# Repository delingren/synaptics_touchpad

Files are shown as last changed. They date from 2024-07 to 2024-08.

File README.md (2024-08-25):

# Laptop Touchpad Project

## Context

I harvested a touchpad from an old HP Envy Sleekbook 6 and wanted to use it as a standalone mouse. It's a clickpad. I.e. it has only one physical button and right click is simulated in software.

Goals:
* Cursor movements.
* Left click and right click (with two fingers).
* Two-finger scrolling.
* Make an enclosure with a USB-C connector.

Status:
* Everything listed above is fully implemented.
* No rigorous testing has been done.
* Some basic error handling is done.
* I have no problem using it as a daily drive.

Most laptop touchpads are made by Synaptics. They usually use a PS/2 interface. By default (i.e. without any special drivers), they can usually simulate a regular PS/2 mouse. I.e. they can report finger movements and button clicks. But that's about it. They don't support more sophisticated gestures we normally find on laptops. To achieve those gestures, we need to implement proprietary but published (with some caveats) Synaptics protocols, documented in [Synaptics PS/2 TouchPad Interfacing Guide](touchpad_RevB.pdf).

## Touchpad info
* Pulled from an HP Envy Sleekbook 6
* Synaptics chip # T1320A
* Pinout, reverse engineered after watching this [YouTube video](https://www.youtube.com/watch?v=XdznW0ZuzGo&t=381s)
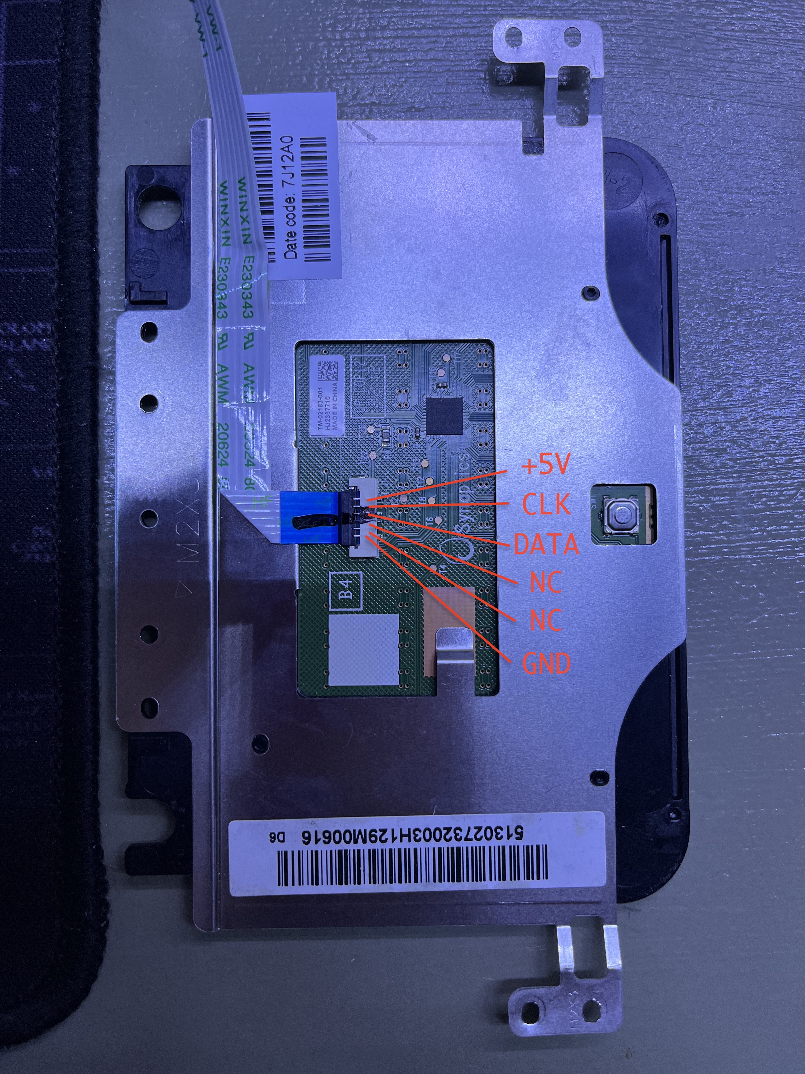
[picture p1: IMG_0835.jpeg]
Pinout


More info obtained from programatic queries, based on section 4.4. Information queries.

* Query 0x00 (Identify TouchPad): 01 47 18. 
  - Version 8.1

* Query 0x01 (Read TouchPad Modes): 20 87 40.
  - Model 0x0887

* Query 0x02 (Read Capabilities): D0 01 23
   - Extended capability: yes 
   - Extended queries: 13
   - Middle button: no
   - Model sub number: 01
   - Pass through: no
   - Low power: no
   - Multi finger report: yes
   - Can sleep: no
   - Four buttons: no
   - Ballitics: no
   - Multi finger detect: yes
   - Palm detect: yes

* Query 0x03 (Read Model ID): 01 E2 B1
  - Absolute mode: yes
  - Geometry: rectangule

* Query 0x06 (Read Serial Number Prefix): 00 00 00

* Query 0x07 (Read Serial Number Suffix): 00 00 00

* Query 0x08 (Read Resolutions): 2F 80 42
  - x units per mm: 47
  - y units per mm: 66
  
* Query 0x09 (Extended Model ID): 84 03 00
  - Light control: no
  - Peak detect: no
  - Glass pass: no
  - Vertical wheel: no
  - Ext. W mode: yes
  - H Scroll: no
  - V Scroll: no
  - Extended buttons: 0
  - Product ID: 0x00

* Query 0x0C (Continued Capabilities): 12 6C 00
  - Covered Pad Gesture: no
  - MultiFinger Mode: 1.0
  - Advanced Gestures: no
  - ClearPad: no
  - Reports Max Coordinates: yes
  - TouchButton Adjustable Threshold: no
  - InterTouch: yes
  - Reports Min Coordinates: yes
  - Uniform ClickPad: no (Hinged mechanism)
  - Reports V: yes
  - No Absolute Position Filter: no
  - Deluxe LEDs: no
  - ClickPad: One-button ClickPad

* Query 0x0D (Maximum Coordinates): B1 6B 94
  - max x: 5686 
  - max y: 4748

* Query 0x0F (Minimum Coordinates): 27 94 22
  - min x: 1256
  - min y: 1106

## Development setup
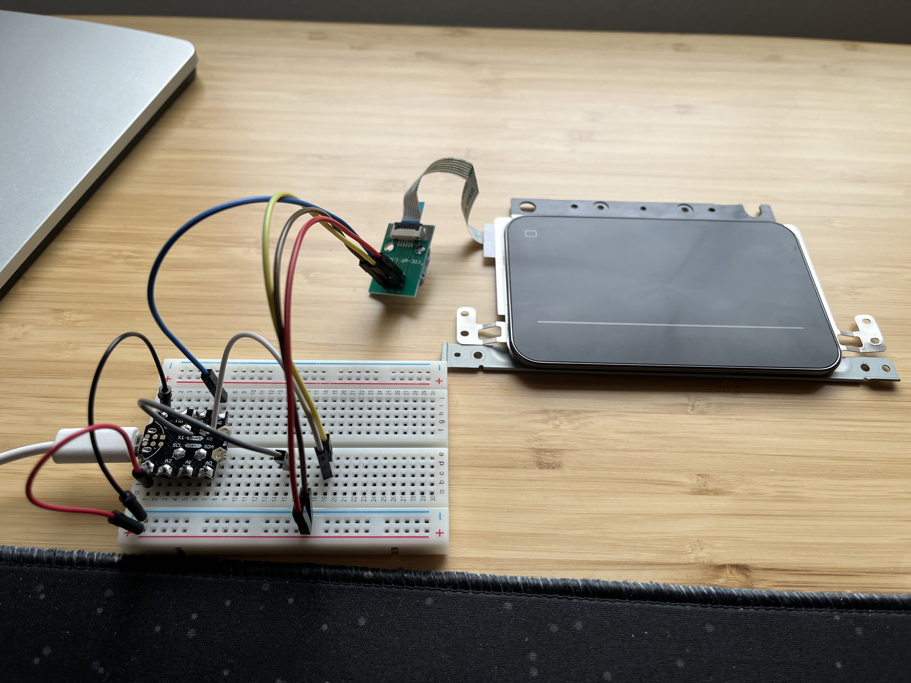
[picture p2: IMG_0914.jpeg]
Breadboard


## Implementing PS/2 on an MCU
I'm using an atmel mega32u4 to interface with the touchpad. Any Leonardo clone should work. The reason I picked this MCU is its native USB support. It also has a 5V logic level, which is what PS/2 uses, so there's no need for a level shifter. Another alternative is to use tinyusb library to bit bang USB protocol on supported MCUs. It's probably pretty straight-forward too.

Basically, I implemented syncrhonous writing, synchronous reading, and asynchronous reading. Synchronous writing because async writing is difficult to use. However, given the async nature of PS/2 protocol, it makes sense to have async, interrupt based reading. I.e. bits are transferred via interrupts and stored in a buffer. I have also implemented synchronous reading as a means to read responses after each write.

 I'm using [external interrupts](https://developerhelp.microchip.com/xwiki/bin/view/products/mcu-mpu/8-bit-avr/structure/extint/) to interact with the clock pin. So the clock pin needs to be one of these: 0, 1, 2, 3, 7 (D2, D3, D1, D0, E6, respectively). It's also possible to use pin change interrupts with slight changes to the code:

```
*(digitalPinToPCICR(clock_pin)) |= 1 << digitalPinToPCICRbit(clock_pin);
*(digitalPinToPCMSK(clock_pin)) |= 1 << digitalPinToPCMSKbit(clock_pin);

... 

ISR(PCINT0_vect) {
   ...
}
```

With the PS/2 protocol implemented, it's really straight-forward to interact the touchpad as a standard PS/2 mouse. The code is [here](https://github.com/delingren/ps2_mouse).

The rest of this doc focuses on the proprietary Synaptics expansion of the PS/2 protocol.

## Data packets
The touchpad sends 6-byte packets to the host. These packets contain information such as finger positions, pressure, width. This particular touchpad can detect 3 fingers. But it only reports the positions of two. When more than one finger is pressed, it reports the states of two fingers in alternating packets.

Since the communication is inevitably noisy, packets could be lost or altered. And it's not very critical to catch each and every frame. Some packets have distinctive features (e.g. fixed bits at certain places) and can be used as synchronization and recovery packets. So if an unexpected packet is received, I keep discarding packets until I'm in sync again.

## State machine logic
I am simulating the behaviour of a MacBook since that's what I'm used to. Most PC laptops behave the same too, with "tap to click" feature turned off. In the following text, whenever I say "two fingers", I mean two or more fingers.

For now, we only do tracking, scrolling, left and right buttons, where right button click is simulated with a two finger click, just like MacBook. Windows optionally supports this too, as long as the touchpad is multi-touch.

The logic is quite complicated. I might need to give it a little more thought and simplify a little. For now, we have three main valid states, identified by two state variables, finger count and button state. Finger count is the number of fingers on the pad. Button state is a bitmap representing the states of left and right buttons.

### Idle
This is where no fingers are on the touchpad. Conditions:
* finger count == 0
Note that even when there's no fingers are pressed, the button could still be pressed, by a non captive object such as a pen.

### Tracking
This is the state where we report the coordinate delta to the OS who will move the cursor accordingly. There are a couple of substates. conditions:
* finger count == 1 || finger count == 2 && button state != 0

When one finger is pressed, we're tracking regardless if the button is pressed. When two fingers are pressed and the button is *not* pressed, we always scroll. But if two fingers are pressed and the button is also pressed, we also track. This is MacBook's behaviour, which is different from Windows, at least Windows 11 on an HP Envy x360.

### Scrolling
This is the state where two fingers are on the pad and their vertical movements are treated as scrolling. Conditions:
* finger count == 2 || button state == 0

## Optimizations

### Smoothing
I found that if we faithfully report the finger positions in each frame, the cursor wobbles a lot, due to inherent noise and instability of human fingers. To mitigate, a few mechanisms are implemented:

* Averaging. Instead of reporting the position of each frame, I keep track of the average of last 5 frames, to remove sudden movements. I copied some of the logic from [VoodooPS2 driver](https://github.com/acidanthera/VoodooPS2/blob/master/VoodooPS2Trackpad/VoodooPS2TrackpadCommon.h).
* Noise threshold. If the delta between two frames is below a threshold, we assume it's not intentional. The number is emperical and I fine tuned it a few iterations to a place where I'm happy with false positives and false negatives.
* Snapping to the still position. When the finger has been saying still, we use a higher threshold, to make it a little "sticky" to start, but smoother once it's moving. 
* Fat finger and heavy finger. When the finger pressure is high or the width is big, we increase the threshold too, asssuming the finger is less stable. I am still not happy with this optimization. It's still pretty wobbly. But if I increase the threshold too much, it becomes too insensitive. The other day, when I was using a ThinkPad X1, I noticed this behaviour: if the finger width becomes big while tracking, it completely freezes the movement of that finger, until it is lifted, even if the width goes down again. I might want to prototype this behaviour and see if it helps.

### Precision Scrolling
Scrolling seems to have much less granularity. The HID report uses an integer. I find it quite jumpy to even report an amount of 1 in each frame. The reason is the frame rate is too high. But we can't report a fraction of a unit in a frame.

So, I decided to have two scrolling intentions: precision scrolling and fast scrolling. When the finger movements are slow and small, I only generate a report every few frames, and the movement is only 1. Once the speed has passed a certain threshold, I assume the user's intention is to quickly scroll over a big area. In this case, I report each frame and the amount is proportional to the actual movement.

### Freezing before button press and after button release
One thing I noticed is that the finger tends to be very unstable while pressing or releasing the button. So I try to freeze the finger movement (report a delta of 0) during these moments.
* Releasing is relatively easy. I have a global frame count which increases by 1 each time a packet arrives. When the button is released, I remember the frame count. Then in the next few frames, I always report the position delta as 0.
* Pressing is much trickier. By the time we realize a button has been pressed, the instability has already happened. In order to change frames retrospectively, I implemented a delayed reporting mechanism. Each time we want to send an HID report, we put it in a queue. And we send a report a few frames after it has been generated. We need to make this delay really small (just 3 or 4 frames) to be unnoticable.

## TODOs
* Make it more stable with thumb clicks. I'm still a little unhappy when I use the thumb to press the button and another finger to move the cursor. I use this a lot to select text. The thumb position is not very stable although my intention is to keep it still. This can probably be improved by checking the width of the finger, which is reported. A fat finger probably should be given more leeway when it comes to determining the movements. The idea I got from ThinkPad might be helpful here.
* ~~Make it more stable when lifting a finger. Lifting a finger tends to brush it over the touchpad and create an unwanted movement. Since we already have a delayed reporting in place, I think we can just go back and change the last few frames when we detect a finger lift.~~
* Tap as click. I was originally against this idea. But it's been growing on me after daily driving a bunch of PC laptops. It's kinda convenient, I have to admit. And it shouldn't be too hard to implement: a short session where the finger movements have never exceeded the noise threshold, we send a button down and a button up reports.
* Horizontal scrolling. I think this is a standard USB HID feature and should be relatively easy to implement. I need to check the USB HID spec, which is very dry to read.
* Three finger swipes as back or forward button. USB HID supports at least 5 buttons so this should be doable.
* Zooming with two fingers. I'm not sure if this is doable, unless we make it into a digitizer.
* Velocity tracking and inertia. If we keep track of the speed of the movements, we can implement a lot of interesting features. One example is inertia, where if you've been scrolling, after the fingers have been released, it still keeps going for a little, slowing down gradually. Another potential application is to keep the noise tolerance high at zero/very low speed, reducing it once the fingers are moving. This way, we can provide better precision control at low speed.

## Enclosure
I designed the enclosure in Fusion 360 and 3D printed it. The stl and original f3d files can be found under `enclosure` folder. I used a ProMicro clone with a USB-C connector. It has the same footprint as the original ProMicro.

The end result:

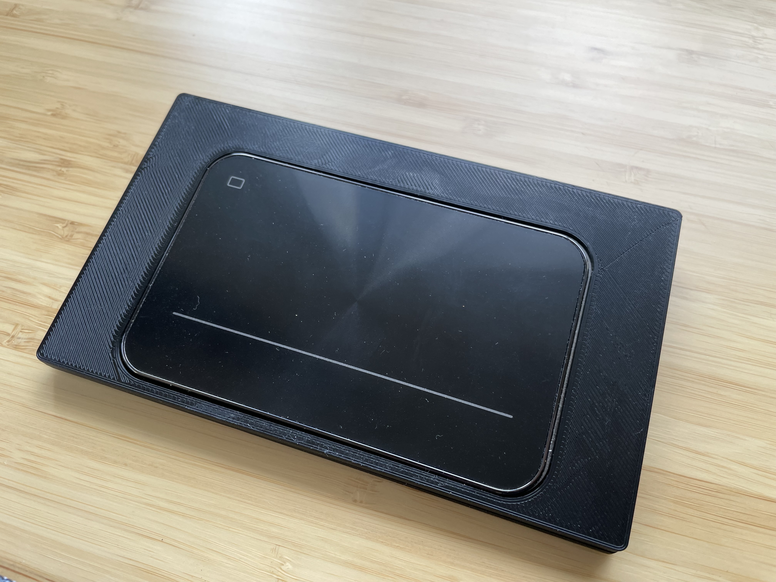
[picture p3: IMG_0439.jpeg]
End result


In action:

In action

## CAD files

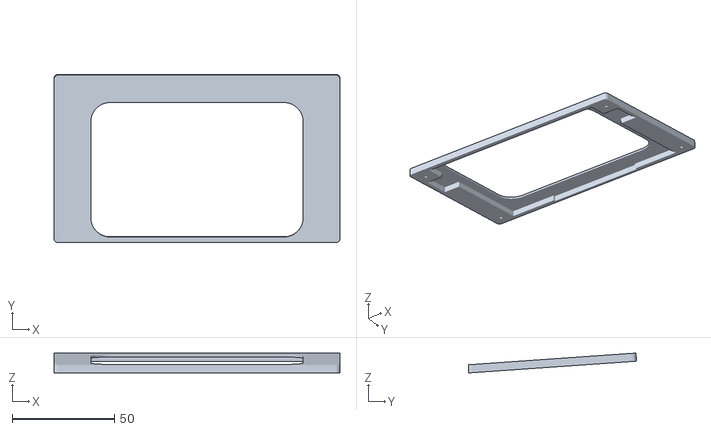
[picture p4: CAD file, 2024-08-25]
enclosure/upper.stl
140.0 x 82.3 x 9.75

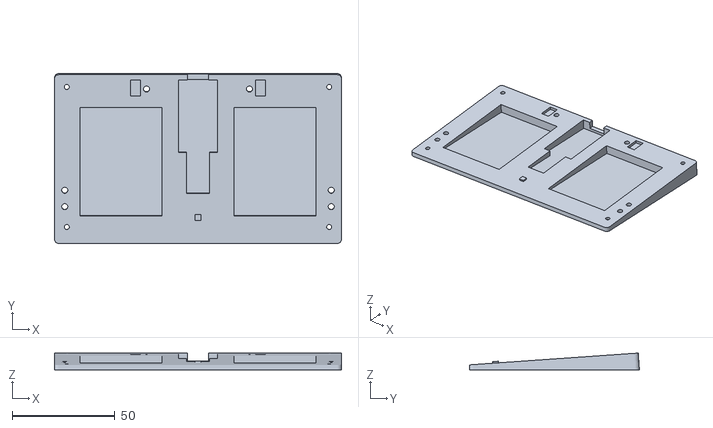
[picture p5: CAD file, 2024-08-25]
enclosure/lower.stl
140.0 x 82.9 x 8.25

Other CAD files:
enclosure/enclosure.f3d

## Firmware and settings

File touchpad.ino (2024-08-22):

// The MIT License (MIT)

// Copyright (c) 2024 Deling Ren

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
#include "src/hid.h"
#include "src/ps2.h"
#include "src/synaptics.h"

#ifndef min
#define min(a, b) ((a) < (b) ? (a) : (b))
#endif

#ifndef max
#define max(a, b) ((a) > (b) ? (a) : (b))
#endif

#ifndef sign
#define sign(x) ((x) > 0 ? (1) : ((x) < 0 ? (-1) : (0)))
#endif

// All the following consts are empirical and may vary from person to person and
// from device to device. These values are a good place to start. I may keep
// fine turning them.

// When finger is held *still*, the maximum flucation from frame to frame in mm.
const float noise_threshold_tracking_mm = 0.08;
const float noise_threshold_scrolling_mm = 0.09;

// In order to retrospectively change the frames in the past, we delay reporting
// for a few frames. This needs to be short enough that it's not perceptible.
const int frames_delay = 6;
// After the button is released, we freeze for a few frames since the finger is
// likely going to be very unstable. Since it's very hard to release the button
// and start moving immediately, it's OK to keep this frozen period relatively
// long.
const int frames_stablization = 15;

// HID units per mm, when tracking.
const float scale_tracking_mm = 12.0;
// HID units per mm, when scrolling.
const float scale_scroll_mm = 1.6;
// Cutoff speed between slow and fast scrolling, in mm/frame.
const float slow_scroll_threshold_mm = 2.0;
// Max distance between two frames.
const float max_delta_mm = 3;
// The delta in either direction within which is considered normal movements
// between frames while scrolling at a moderate speed.
const int proximity_threshold_mm = 15;
// The amount of scroll per detent, in HID units
const float slow_scroll_amount = 0.20F;

// HID units per raw unit, when tracking.
float scale_tracking_x, scale_tracking_y;
// UID units per raw unit, when scrolling.
float scale_scroll;
// Max fluctuation from frame to frame in raw units.
float noise_threshold_tracking_x, noise_threshold_tracking_y;

float noise_threshold_scrolling_y;

// Max distance from frame to frame in raw units.
float max_delta_x, max_delta_y;
// Cutoff speed between slow and fast scrolling, in raw units per frame.
float slow_scroll_threshold;
// The delta within which is considered normal movements between frames while
// scrolling at a moderate speed.
float proximity_threshold_x, proximity_threshold_y;

struct finger_state {
  SimpleAverage<int, 5> x;
  SimpleAverage<int, 5> y;
  short z;
};

struct report {
  uint8_t buttons;
  int8_t x;
  int8_t y;
  int8_t scroll;
};

// In reality we don't really need a ring buffer for packets. A 16MHz ATMega32U4
// can easily handle 80 frames per second without skipping frames.
RingBuffer<uint64_t, 4> packets;
RingBuffer<report, 32> reports;

static unsigned long global_tick = 0;
static unsigned long session_started_tick = 0;
static unsigned long button_released_tick = 0;

// State of primary and secondary fingers. We only keep track of two since this
// touchpad doesn't report the position of the 3rd and doesn't register the 4th.
static finger_state finger_states[2];
static short finger_count = 0;
static uint8_t button_state = 0;  // bit 0: L, bit 1: R

const uint8_t LEFT_BUTTON = 0x01;
const uint8_t RIGHT_BUTTON = 0x02;

void byte_received(uint8_t data) {
  static uint64_t buffer = 0;
  static int index = 0;

  if (index == 0 && (data & 0xc8) != 0x80) {
    Serial.print("Unexpected byte0 data ");
    Serial.println(data, HEX);

    index = 0;
    buffer = 0;
    return;
  }

  if (index == 24 && (data & 0xc8) != 0xc0) {
    Serial.print("Unexpected byte3 data ");
    Serial.println(data, HEX);

    index = 0;
    buffer = 0;
    return;
  }

  buffer |= ((uint64_t)data) << index;
  index += 8;
  if (index == 48) {
    packets.push_back(buffer);
    index = 0;
    buffer = 0;
  }
}

void process_pending_packet(uint64_t packet) {
  global_tick++;
  uint8_t w =
      (packet >> 26) & 0x01 | (packet >> 1) & 0x2 | (packet >> 2) & 0x0C;

  // When parsing packets, we queue the reports instead of send them directly.
  // Then we delay sending them for a few frames, to give us an opportunity to
  // retrospectively change the reports.
  // We produce at most one report per frame. So we only need to send one
  // pending report per frame. Once all activities ceased, the touchpad keeps
  // sending packets with x, y, and z all set to 0 for one second. And we only
  // report the first one. That means, we have plenty of time to clear up the
  // report queue, which we need to do. Otherwise the queue will get clogged up
  // soon, and reports leak to the next session, causing weird behaviors.
  if (global_tick - session_started_tick >= frames_delay) {
    if (!reports.empty()) {
      report item = reports.pop_front();
      hid::report(item.buttons, item.x, item.y, item.scroll);
    }
  }

  switch (w) {
    case 3:  // pass through
      return;
    case 2:  // extended w mode
      parse_extended_packet(packet);
      return;
    default:
      parse_primary_packet(packet, w);
      return;
  }
}

float to_hid_value(float value, float threshold, float scale_factor) {
  const float hid_max = 127.0F;
  if (abs(value) < threshold) {
    return 0;
  }
  return sign(value) * min(max(abs(value) * scale_factor, 1.0F), hid_max);
}

void queue_report(uint8_t buttons, int8_t x, int8_t y, float scroll) {
  static float scroll_amount_rollover = 0;
  report item = {.buttons = buttons};
  if (button_released_tick != 0 &&
      global_tick - button_released_tick < frames_stablization) {
    // When a button is released, we freeze the next few frames.
    item.x = 0;
    item.y = 0;
    item.scroll = 0;
  } else {
    if (scroll > -1.0F && scroll < 1.0F) {
      scroll_amount_rollover += scroll;
      if (scroll_amount_rollover >= 1.0F) {
        scroll = 1.0F;
        scroll_amount_rollover -= 1.0F;
      } else if (scroll_amount_rollover <= -1.0F) {
        scroll = -1.0F;
        scroll_amount_rollover += 1.0F;
      } else {
        scroll = 0;
      }
    }
    item.x = x;
    item.y = y;
    item.scroll = scroll;
  }
  reports.push_back(item);
}

void parse_primary_packet(uint64_t packet, int w) {
  // Reference: Section 3.2.1, Figure 3-4
  int x = (packet >> 32) & 0x00FF | (packet >> 0) & 0x0F00 |
          (packet >> 16) & 0x1000;
  int y = (packet >> 40) & 0x00FF | (packet >> 4) & 0x0F00 |
          (packet >> 17) & 0x1000;
  short z = (packet >> 16) & 0xFF;
  // w is width only if it >= 4. otherwise it encodes finger count
  short width = max(w, 4);

  // A clickpad reprots its button as a middle/up button. This logic needs to
  // change completely if the touchpad is not a clickpad (i.e. it has physical
  // buttons).
  bool button = (packet >> 24) & 0x01;
  int new_finger_count = 0;
  if (z == 0) {
    new_finger_count = 0;
  } else if (w >= 4) {
    new_finger_count = 1;
  } else if (w == 0) {
    new_finger_count = 2;
  } else if (w == 1) {
    new_finger_count = 3;
  }

  if (finger_count == 0 && new_finger_count > 0) {
    session_started_tick = global_tick;
  }

  /* Mechanisms to smooth the movements. */

  // When a button is pressed, we retrospectively freeze the previous frames,
  // since the movements tend to be jerky when releasing a button.
  if (button && button_state == 0) {
    int size = reports.size();
    for (int i = 0; i < size; i++) {
      reports[i].x = 0;
      reports[i].y = 0;
      reports[i].scroll = 0;
    }
  }

  // When a button is released, we freeze the next few frames, since the
  // movements tend to be jerky when pressing a button.
  if (!button && button_state != 0) {
    button_released_tick = global_tick;
  }

  // When a finger is lifted, we restrospectively freeze the previous
  // frames, since the movements tend to be jerky when lifting a finger.
  if (new_finger_count < finger_count) {
    for (int i = 0; i < reports.size(); i++) {
      reports[i].x = 0;
      reports[i].y = 0;
      reports[i].scroll = 0;
    }
  }

  /* Update state variables. */
  if (new_finger_count > finger_count) {
    // A finger has been added. Reset state for that finger.
    finger_states[1].x.reset();
    finger_states[1].y.reset();
    if (finger_count == 0) {
      finger_states[0].x.reset();
      finger_states[0].y.reset();
    }
  }

  int delta_x = 0, delta_y = 0;

  if (new_finger_count > 0) {
    finger_states[0].z = z;

    int prev_x = finger_states[0].x.average();
    int new_x = finger_states[0].x.filter(x);
    if (prev_x > 0 && new_finger_count == finger_count) {
      delta_x = new_x - prev_x;
    }

    int prev_y = finger_states[0].y.average();
    int new_y = finger_states[0].y.filter(y);
    if (prev_y > 0 && new_finger_count == finger_count) {
      delta_y = new_y - prev_y;
    }
  }

  if (new_finger_count < finger_count) {
    // A finger has been released.
    if (finger_count == 2) {
      // 2 fingers -> 1 finger
      // When a primary finger is released, the secondary becomes the primary.
      // We determine if that is happening by checking if the finger location is
      // close to the previous secondary finger. proximity_threshold is an
      // emperical number and not always reliable. We err on the conservative
      // side. If we can't be sure, just reset the state. This could result in a
      // slightly jerky cursor movement.
      if (abs(x - finger_states[0].x.average()) >= proximity_threshold_x ||
          abs(y - finger_states[0].y.average()) >= proximity_threshold_y) {
        if (abs(x - finger_states[1].x.average()) < proximity_threshold_x &&
            abs(y - finger_states[1].y.average()) < proximity_threshold_y) {
          finger_states[0] = finger_states[1];
        } else {
          finger_states[0].x.reset();
          finger_states[0].y.reset();
        }
      }
    } else {
      // 3 fingers -> 2 fingers or 1 finger, or all fingers have been lifted.
      // Let's not bother. Just reset both fingers.
      finger_states[0].x.reset();
      finger_states[0].y.reset();
      finger_states[1].x.reset();
      finger_states[1].y.reset();
    }
  }

  if (finger_count == 1 && new_finger_count == 1 &&
      (abs(delta_x) >= max_delta_x || abs(delta_y) >= max_delta_y)) {
    // In rare occasions where a finger is released and another is pressed in
    // the same frame, we don't see a finger count change but a big jump in
    // finger position. In this case, reset the position and start over.
    // This solution isn't ideal. A rather big jump could happen when the
    // fingers are moving very fast. A more reliable approach would be based
    // on the recent velocity of the finger movements. But it's complicated
    // and expensive. Both scenarios just described are edge cases and the user
    // is probably just fooling around.
    finger_states[0].x.reset();
    finger_states[0].y.reset();
    delta_x = 0;
    delta_y = 0;
  }

  finger_count = new_finger_count;

  /* State machine logic */
  if (finger_count == 0) {
    // idle
    if (button_state == 0 && button) {
      button_state = new_finger_count < 2 ? LEFT_BUTTON : RIGHT_BUTTON;
      queue_report(button_state, 0, 0, 0);
    } else if (button_state != 0 && !button) {
      button_state = 0;
      queue_report(0, 0, 0, 0);
    }
  } else if (finger_count >= 2 && button_state == 0) {
    // scrolling
    if (button) {
      // It's OK to change between left and right while scrolling.
      button_state = new_finger_count > 1 ? RIGHT_BUTTON : LEFT_BUTTON;
    } else {
      button_state = 0;
    }

    // Since we're scrolling, we are here every other frame. So we should double
    // the noise threshold.
    float scroll_amount =
        to_hid_value(delta_y, noise_threshold_scrolling_y, scale_scroll);
    if (abs(delta_y) <= slow_scroll_threshold) {
      scroll_amount = sign(scroll_amount) * slow_scroll_amount;
    }
    queue_report(button_state, 0, 0, scroll_amount);
  } else if (finger_count == 1 || finger_count >= 2 && button_state != 0) {
    // 1-finger tracking or 2-finger tracking
    if (button) {
      // If the button is already pressed, we don't change between left and
      // right while dragging.
      if (button_state == 0) {
        button_state = new_finger_count > 1 ? RIGHT_BUTTON : LEFT_BUTTON;
      }
    } else {
      button_state = 0;
    }
    // If there are multiple fingers pressed, normal packets and secondary
    // packets are alternated. So we should double the threshold.
    float threshold_multiplier = finger_count == 1 ? 1.0 : 2.0;
    // Serial.print("Width: ");
    // Serial.print(width);
    // Serial.print(" Pressure: ");
    // Serial.println(z);

    if (width > 4) {
      // Fat finger
      threshold_multiplier *= 1.0F + (width - 4.0F) / 4.0F;
    }
    if (z >= 60) {
      // Heavy finger
      threshold_multiplier *= 1.0F + (z - 60.0F) / 40.0F;
    }

    float delta_x_mm = ((float)delta_x) / ((float)synaptics::units_per_mm_x);
    float delta_y_mm = ((float)delta_y) / ((float)synaptics::units_per_mm_y);
    // Precision for low speed and range for high speed. If there are more than
    // one finger the speed needs to be doubled.
    float velocity = sqrt(delta_x_mm * delta_x_mm + delta_y_mm * delta_y_mm);
    if (finger_count > 1) {
      velocity *= 2;
    }
    float scale_multiplier = 1.0F + velocity * 0.5F;  // Emperical constant

    int8_t delta_x_hid =
        to_hid_value(delta_x, noise_threshold_tracking_x * threshold_multiplier,
                     scale_tracking_x * scale_multiplier);
    int8_t delta_y_hid = -to_hid_value(
        delta_y, noise_threshold_tracking_y * threshold_multiplier,
        scale_tracking_y * scale_multiplier);
    queue_report(button_state, delta_x_hid, delta_y_hid, 0);
  }
}

void parse_extended_packet(uint64_t packet) {
  uint8_t packet_code = (packet >> 44) & 0x0F;
  if (packet_code == 1) {
    // Reference: Section 3.2.9.2. Figure 3-14
    int x = (packet >> 7) & 0x01FE | (packet >> 23) & 0x1E00;
    int y = (packet >> 15) & 0x01FE | (packet >> 27) & 0x1E00;
    short z = (packet >> 39) & 0x1D | (packet >> 23) & 0x60;

    if (x == 0 || y == 0 || z == 0) {
      finger_states[1].x.reset();
      finger_states[1].y.reset();
      return;
    }

    int prev_x = finger_states[1].x.average();
    int new_x = finger_states[1].x.filter(x);
    int delta_x = prev_x == 0 ? 0 : new_x - prev_x;

    int prev_y = finger_states[1].y.average();
    int new_y = finger_states[1].y.filter(y);
    int delta_y = prev_y == 0 ? 0 : new_y - prev_y;

    if (abs(delta_x) >= max_delta_x || abs(delta_y) >= max_delta_y) {
      // Sometimes when a 2nd or 3rd finger is released, we receive a secondary
      // finger position before the finger count change. In this case, the new
      // secondary finger is not necessarily the same physical finger as
      // previous one. Not sure if this is by design or due to a packet loss.
      // In either case, we should not report this position change to avoid
      // jerky movements. Instead, reset the secondary finger state and start
      // over.
      finger_states[1].x.reset();
      finger_states[1].y.reset();
      delta_x = 0;
      delta_y = 0;
    }

    finger_states[1].x.filter(x);
    finger_states[1].y.filter(y);
    finger_states[1].z = z;

    // TODO: use velocity and z value to adjst the multiplier here too, just
    // like the primary frames. We don't have width info though.
    if (finger_count >= 2 && button_state == 0) {
      // Since we are parsing secondary packets, we are here every other frame,
      // so we should double the noise threshold.
      float scroll_amount =
          to_hid_value(delta_y, noise_threshold_scrolling_y, scale_scroll);
      if (abs(delta_y) <= slow_scroll_threshold) {
        scroll_amount = sign(scroll_amount) * slow_scroll_amount;
      }
      queue_report(button_state, 0, 0, scroll_amount);
    } else {
      int8_t delta_x_hid = to_hid_value(
          delta_x, noise_threshold_tracking_x * 2.0F, scale_tracking_x);
      int8_t delta_y_hid = -to_hid_value(
          delta_y, noise_threshold_tracking_y * 2.0F, scale_tracking_y);
      queue_report(button_state, delta_x_hid, delta_y_hid, 0);
    }
  }
}

void setup() {
  Serial.begin(115200);
  hid::init();
  // The pins are quite noisy on startup. Let's wait for a bit before starting
  // the touchpad. 500ms seems to be a good time. It's still not bullet proof
  // but the error handling mechanism seems to be able to recover every time.
  delay(500);
  ps2::begin(0, 1, byte_received);
  ps2::reset();
  synaptics::init();

  scale_tracking_x = scale_tracking_mm / synaptics::units_per_mm_x;
  scale_tracking_y = scale_tracking_mm / synaptics::units_per_mm_y;
  scale_scroll = scale_scroll_mm / synaptics::units_per_mm_y;
  noise_threshold_tracking_x =
      noise_threshold_tracking_mm * synaptics::units_per_mm_x;
  noise_threshold_tracking_y =
      noise_threshold_tracking_mm * synaptics::units_per_mm_y;
  noise_threshold_scrolling_y =
      noise_threshold_scrolling_mm * synaptics::units_per_mm_y;
  max_delta_x = max_delta_mm * synaptics::units_per_mm_x;
  max_delta_y = max_delta_mm * synaptics::units_per_mm_y;
  slow_scroll_threshold = slow_scroll_threshold_mm * synaptics::units_per_mm_y;
  proximity_threshold_x = proximity_threshold_mm * synaptics::units_per_mm_x;
  proximity_threshold_y = proximity_threshold_mm * synaptics::units_per_mm_y;
}

void loop() {
  if (!packets.empty()) {
    uint64_t packet = packets.pop_front();
    process_pending_packet(packet);
  }
}

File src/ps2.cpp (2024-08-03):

// The MIT License (MIT)

// Copyright (c) 2024 Deling Ren

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
#include <Arduino.h>
#include "ps2.h"

namespace ps2 {
// Sample code for interacting with a PS2 mouse from a mega32u4.
// Writing is synchronous. Async write is hard for the client to handle.
namespace {  // anonymous namespace to hide code from the client.
// On atmel mega32u4, clock_pin needs to be one of these: 0, 1, 2, 3, 7,
// otherwise, we need to use pin change interrupt.
int clock_pin_;
int data_pin_;
void (*byte_received_)(uint8_t);

void pull_low(uint8_t pin) {
  pinMode(pin, OUTPUT);
  digitalWrite(pin, LOW);
}

void pull_high(uint8_t pin) { pinMode(pin, INPUT_PULLUP); }

uint8_t read_bit() {
  pinMode(data_pin_, INPUT);
  return digitalRead(data_pin_);
}

void write_bit(uint8_t data) {
  pinMode(data_pin_, OUTPUT);
  digitalWrite(data_pin_, data);
}

void wait_clock(uint8_t value) {
  if (value == LOW) {
    pinMode(clock_pin_, INPUT_PULLUP);
  } else {
    pinMode(clock_pin_, INPUT);
  }

  unsigned long millis_start = millis();
  while (digitalRead(clock_pin_) != value) {
    if (millis() - millis_start > 25) {
      Serial.println("wait_clock timed out.");
      return;
    }
  }
}

volatile int receive_index = 0;
volatile uint8_t receive_buffer = 0;
volatile uint8_t parity = 0;

void disable_interrupt() {
  cli();
  // We need to abandon the ongoing read from the device.
  // Otherwise it'll go haywire next time we enable interrupt.
  receive_index = 0;
  receive_buffer = 0;
  parity = 0;
}

void enable_interrupt() { sei(); }

void bit_received() {
  int clock = digitalRead(clock_pin_);
  if (clock != LOW) {
    return;
  }

  int bit = read_bit();
  if (receive_index == 0) {
    // Start bit
    if (bit != LOW) {
      Serial.println("Start bit error.");
    }
  } else if (receive_index >= 1 && receive_index <= 8) {
    // Payload bit
    receive_buffer |= bit << (receive_index - 1);
    parity ^= bit;
  } else if (receive_index == 9) {
    // Parity bit
    parity ^= bit;
    if (parity != 1) {
      Serial.println("Parity bit error.");
    }

  } else if (receive_index == 10) {
    // Stop bit
    if (bit != HIGH) {
      Serial.println("Stop bit error.");
    }
    byte_received_(receive_buffer);
    receive_buffer = 0;
    receive_index = 0;
    parity = 0;
    return;
  }

  receive_index++;
}

// Reads a byte synchronously. This should only be called from write_byte() to
// read the response and shouldn't be called by the client.
uint8_t read_byte() {
  // Start bit
  wait_clock(LOW);
  uint8_t start_bit = read_bit();
  if (start_bit != LOW) {
    Serial.println("Start bit error.");
  }
  wait_clock(HIGH);

  uint8_t data = 00;
  uint8_t parity = 0;
  for (int i = 0; i < 8; i++) {
    wait_clock(LOW);
    uint8_t bit = read_bit();
    wait_clock(HIGH);

    data |= bit << i;
    parity ^= bit;
  }

  wait_clock(LOW);
  parity ^= read_bit();
  wait_clock(HIGH);
  if (parity != 1) {
    Serial.println("Parity error.");
  }

  wait_clock(LOW);
  uint8_t stop = read_bit();
  if (stop != 1) {
    Serial.println("Stop bit error.");
  }
  pull_low(clock_pin_);
  delayMicroseconds(50);
  pull_high(clock_pin_);

  return data;
}
}  // namespace

bool write_byte(uint8_t data) {
  // Bring CLK low for 100 us.
  pull_low(clock_pin_);
  delayMicroseconds(100);
  // Bring DATA low.
  pull_low(data_pin_);
  // Release CLK
  pull_high(clock_pin_);
  // Now we are in the request-to-send state.

  uint8_t const stop = 1;
  uint8_t parity = 1;

  // bits 0 - 7: payload
  for (int i = 0; i < 8; i++) {
    // Get the LSB
    uint8_t bit = data & 0x01;
    // Update parity
    parity ^= bit;
    // Shift data for next iteration
    data >>= 1;

    // Device samples when CLK is low.
    wait_clock(LOW);
    write_bit(bit);
    wait_clock(HIGH);
  }

  // bit 8: parity
  wait_clock(LOW);
  write_bit(parity);
  wait_clock(HIGH);

  // bit 9: stop
  wait_clock(LOW);
  write_bit(stop);
  wait_clock(HIGH);

  // bit 10: line control
  wait_clock(LOW);
  uint8_t line_control = read_bit();
  wait_clock(HIGH);
  if (line_control != LOW) {
    Serial.println("Line control error.");
  }

  uint8_t ack = read_byte();
  if (ack != 0xFA) {
    Serial.println("Error: did not receive ACK");
    return false;
  }
}

void begin(uint8_t clock_pin, uint8_t data_pin,
           void (*byte_received)(uint8_t)) {
  clock_pin_ = clock_pin;
  data_pin_ = data_pin;
  byte_received_ = byte_received;

  pull_high(clock_pin);
  pull_high(data_pin);

  attachInterrupt(digitalPinToInterrupt(clock_pin_), bit_received, FALLING);
}

bool ps2_command(uint16_t command, uint8_t* args, uint8_t* result) {
  disable_interrupt();

  unsigned int send = (command >> 12) & 0x0F;
  unsigned int receive = (command >> 8) & 0x0F;
  write_byte(command & 0xFF);

  for (int i = 0; i < send; i++) {
    write_byte(args[i]);
  }

  for (int i = 0; i < receive; i++) {
    uint8_t response = read_byte();
    if (result != nullptr) {
      result[i] = response;
    }
  }

  enable_interrupt();
  return true;
}

void reset() { ps2_command(PSMOUSE_CMD_RESET_BAT, nullptr, nullptr); }

void enable() { ps2_command(PSMOUSE_CMD_ENABLE, nullptr, nullptr); }

void disable() { ps2_command(PSMOUSE_CMD_DISABLE, nullptr, nullptr); }

};  // namespace ps2

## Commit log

2024-07-29 Add some query results Print debug info for each packet
2024-07-30 State machine logic. Mostly in place. Known issue: two finger -> one finger transition
    [touchpad.ino]
2024-07-31 Fix the bug where releasing the second finger causes a jump in tracking and scrolling states.
    Clean up a little bit.
    [synaptics.cpp, touchpad.ino]
2024-07-31 Fix bug. Reduce sensitivity when finger is fat.
    [touchpad.ino]
2024-08-02 Fix the issue when the third finger is pressed or released, it gets too jerky.
    [touchpad.ino]
2024-08-03 Oops. Revert an accidental change.
    [synaptics.cpp]
2024-08-03 Implement slow scrolling mode. When every frame is under certain amount, we skip some frames to allow precise scrolling. Once every frame is above the threshold, resume normal scrolling.
    [touchpad.ino]
2024-08-05 Avoid doing floating point calculation in each frame.
    [touchpad.ino]
2024-08-05 Use different noise threshold for tracking and scrolling. Fix a bug.
    [touchpad.ino]
2024-08-06 Bug fix. Number casting in C is evil!
    [touchpad.ino]
2024-08-07 Delay frames and freeze frames
2024-08-07 Use velocity to adjust noise threshold
    [touchpad.ino]
2024-08-07 Adjust threshold based on finger width and pressure, for the primary finger.
2024-08-08 Use accurate velocity.
2024-08-25 Add photos and polish up.
    [enclosure.f3d, lower.stl, upper.stl]
